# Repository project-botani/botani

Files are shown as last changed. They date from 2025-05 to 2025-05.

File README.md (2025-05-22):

# B.O.T.A.N.I - Beobachtender Organischer Topf mit Agiler Navigation und Intelligenz

A smart robotic system for remote plant care, navigation, and monitoring, designed using Raspberry Pis, sensors, and a LEGO vehicle base. B.O.T.A.N.I allows users to drive a plant-bearing vehicle via a custom-built controller equipped with a joystick, LED indicators, a buzzer, and a live video feed.

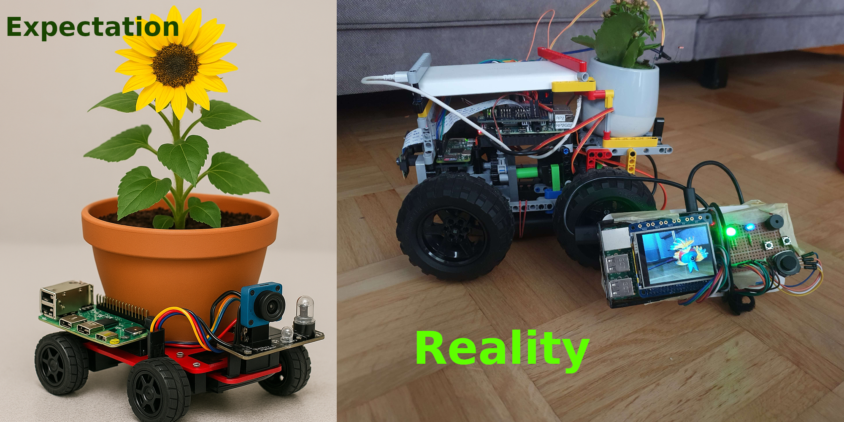
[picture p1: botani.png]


## Project Structure

```
.
├── RaspberryPi3        # Controller hardware: joystick, display, buzzer, LED
│   ├── view_stream.py
│   ├── joystick.py
│   ├── ledcontrol.py
│   └── requirements.txt
├── RaspberryPi4        # Vehicle logic: motors, camera, distance control
│   ├── camera.py
│   ├── motorsteerdistance.py
│   └── requirements.txt
├── RaspberryPiZero     # Sensor node: brightness, temperature, humidity, distance
│   ├── sensors.py
│   └── requirements.txt
├── Dashboard.html      # Web dashboard for live feed and sensor data
├── README.md
└── ProjectReport.pdf   # Full project report
```

## System Overview

B.O.T.A.N.I consists of three main components:

1. **Controller** - A Raspberry Pi 3 with:

   * A PiTFT screen for live video.
   * Joystick for manual control.
   * RGB LED for temperature indication.
   * Buzzer for soil humidity alerts.

2. **Car Platform** - A LEGO-based vehicle powered by Raspberry Pi 4:

   * Servo motors for movement and steering.
   * Time-of-Flight sensor for collision avoidance.
   * Camera for live video stream.

3. **Sensor Node** - Raspberry Pi Zero:

   * Monitors light, temperature, humidity, and distance.
   * Publishes data via MQTT to the controller and web dashboard.

## How to set up the project

To configure all raspberry PIs, this repository needs to be cloned onto each one of them.
This repo contains folders that correspond to the code that needs to run on each one of the PIs.

### 1. Raspberry Pi 3 - Controller

**Dependencies:**

```bash
cd RaspberryPi3
python3 -m venv .venv --system-site-packages
source .venv/bin/activate
pip install -r requirements.txt
```

**Joystick Setup:**

```bash
sudo raspi-config  # Enable I2C
sudo apt install -y i2c-tools
i2cdetect -y 1     # Should detect ADC at 0x48
```

**Configure PiTFT Display:**

```bash
# Install display driver
sudo apt-get update
sudo apt-get install -y git python3-pip
pip3 install --upgrade adafruit-python-shell click
git clone https://github.com/adafruit/Raspberry-Pi-Installer-Scripts.git
cd Raspberry-Pi-Installer-Scripts

sudo -E env PATH=$PATH python3 adafruit-pitft.py --display=28r --rotation=90 --install-type=console

sudo reboot

# Configure rotation if necessary
# (look for line with the tft screen listed)
vim /boot/firmware/config.txt
sudo reboot
```

**Start All Scripts:**

```bash
python3 joystick.py & python3 ledcontrol.py & python3 view_stream.py
```

### 2. Raspberry Pi 4 - Car System

**Dependencies:**

```bash
cd RaspberryPi4
python3 -m venv .venv
source .venv/bin/activate
pip install -r requirements.txt
```

**Run:**

* `camera.py` for streaming video to `http://<car-ip>:8080/`
* `motorsteerdistance.py` to handle drive + safety logic

```bash
python3 camera.py & python3 motorsteerdistance.py
```

### 3. Raspberry Pi Zero - Sensors

**Dependencies:**

```bash
cd RaspberryPiZero
python3 -m venv .venv
source .venv/bin/activate
pip install -r requirements.txt
```

**Run:**

```bash
python3 sensors.py
```

### 4. Dashboard

Open `Dashboard.html` in a somewhat modern browser.
This file is standalone and does not require to be served by a webserver.
Make sure MQTT broker is accessible at `ws://<rpi4-ip>:8081`.

## Communication Overview

### MQTT Topics

| Topic | Publisher | Subscriber(s) | Purpose |
| --- | --- | --- | --- |
| `Brightness`  | Raspberry Pi Zero | Pi 3 (LED), Dashboard | Plant light level |
| `Temperature` | Raspberry Pi Zero | Pi 3 (RGB LED), Dashboard | Ambient temperature |
| `Humidity` | Raspberry Pi Zero | Pi 3 (Piezo buzzer), Dashboard | Soil moisture |
| `Distance` | Raspberry Pi Zero | Pi 4 (Safety), Dashboard | Obstacle distance |
| `joystick/xy` | Raspberry Pi 3 | Pi 4 (motor control) | Drive/steering commands |

### Video Stream

* The MJPEG stream is accessible at `http://<car-ip>:8080/`

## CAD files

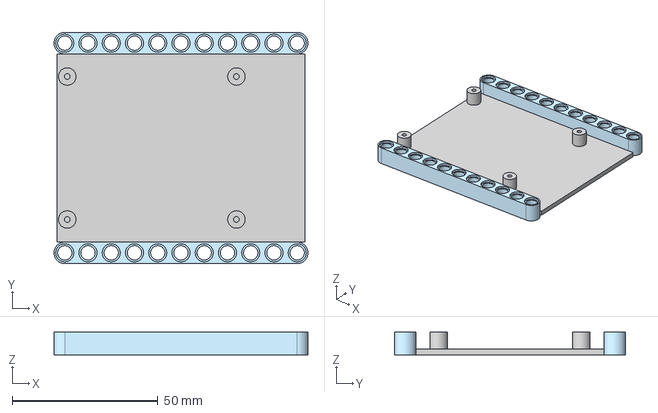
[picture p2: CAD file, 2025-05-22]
3DModels/RaspberryPiLegoMount.step
87.1 x 79.3 x 7.76 mm

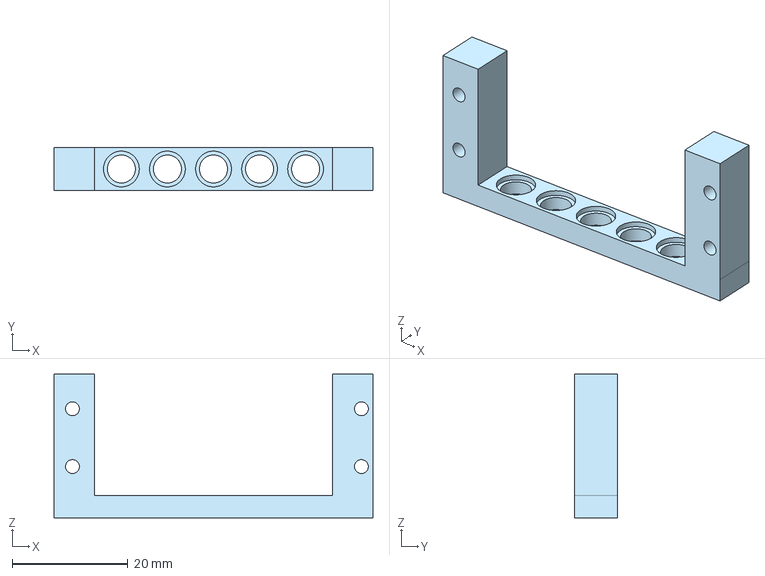
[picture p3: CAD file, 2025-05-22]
3DModels/MotorMount_Steering.step
55.2 x 7.38 x 24.9 mm

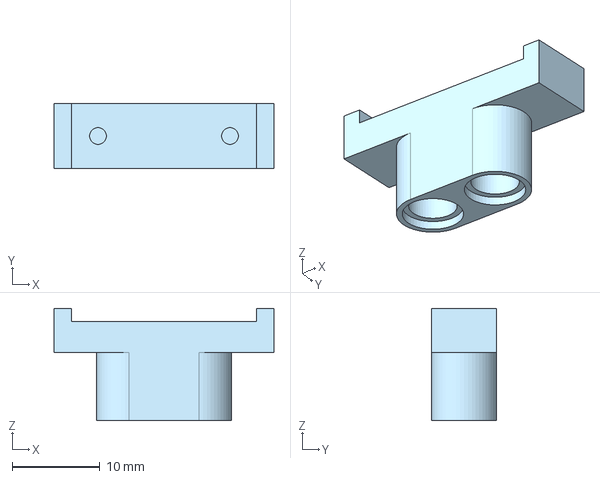
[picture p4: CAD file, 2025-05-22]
3DModels/ToF_Mount.step
25.0 x 7.38 x 12.8 mm

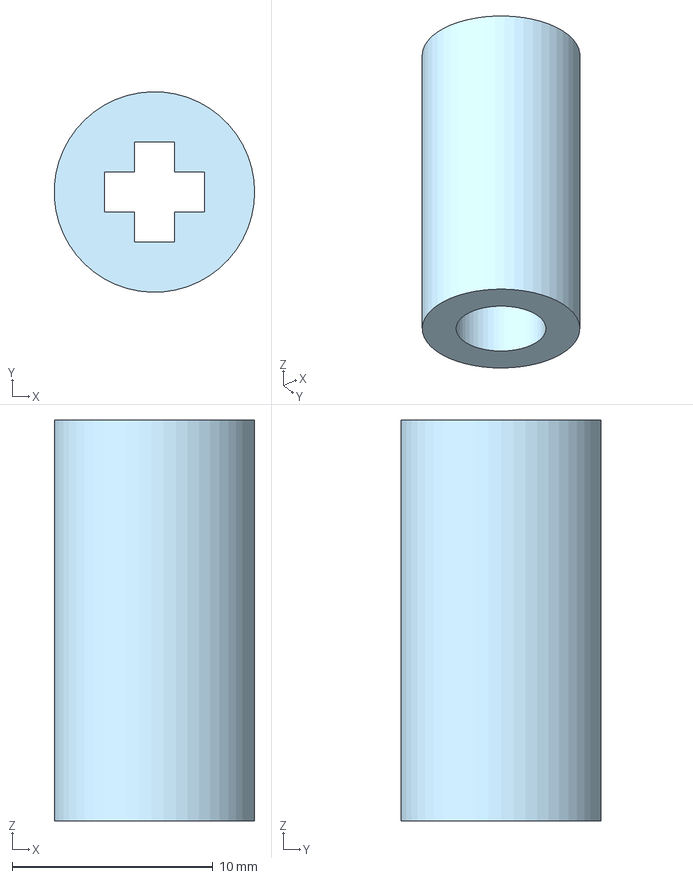
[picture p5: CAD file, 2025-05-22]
3DModels/ServoToLegoAxleInput.step
9.99 x 10.00 x 20.0 mm

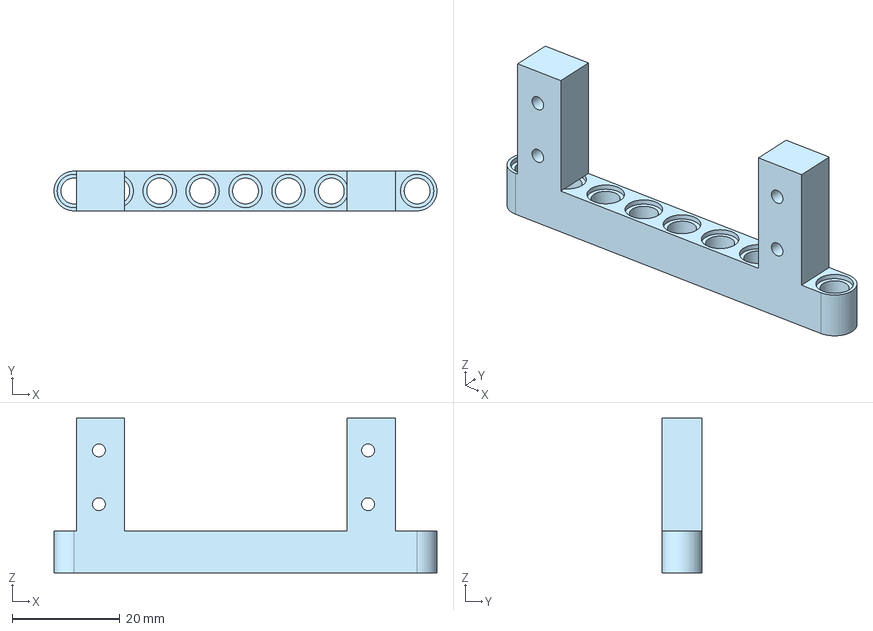
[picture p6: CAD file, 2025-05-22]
3DModels/MotorMount_Drive.step
71.1 x 7.38 x 28.8 mm

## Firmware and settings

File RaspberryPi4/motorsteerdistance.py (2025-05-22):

import json
import signal
import sys
import time
import threading

import paho.mqtt.client as mqtt
from adafruit_servokit import ServoKit

MQTT_BROKER      = "localhost"
MQTT_PORT        = 1883
JOYSTICK_TOPIC   = "joystick/xy"
DISTANCE_TOPIC   = "Distance"

STEER_SERVO_CH       = 13
DRIVE_SERVO_CH       = 15
DEAD_ZONE            = 0.05
STEER_SPEED          = 0.09
STEER_TRAVEL_TIME_L  = 0.9
STEER_TRAVEL_TIME_R  = 1.0
LOOP_INTERVAL        = 0.02
RECONNECT_DELAY      = 5

kit = ServoKit(channels=16)

_current_x = 0.0
_target_x  = 0.0
_distance  = 255
_lock      = threading.Lock()
_running   = True

def clamp(v, lo=-1.0, hi=1.0):
    return max(lo, min(hi, v))

def on_connect(client, _userdata, _flags, rc):
    client.subscribe(JOYSTICK_TOPIC)
    client.subscribe(DISTANCE_TOPIC)

def on_disconnect(client, _userdata, rc):
    while _running:
        try:
            client.reconnect()
            return
        except Exception:
            time.sleep(RECONNECT_DELAY)

def on_message(client, _userdata, msg):
    global _target_x, _distance

    topic = msg.topic
    payload = msg.payload.decode().strip()

    if topic == DISTANCE_TOPIC:
        try:
            d = float(payload)
            if 0.00 <= d <= 255.00:
                _distance = d
        except ValueError:
            pass
        return

    if topic == JOYSTICK_TOPIC:
        try:
            if payload.startswith("{"):
                data = json.loads(payload)
                x, y = float(data["x"]), float(data["y"])
            else:
                x_str, y_str = payload.split(",", 1)
                x, y = float(x_str), float(y_str)

            x = 0.0 if abs(x) < DEAD_ZONE else clamp(x)
            y = 0.0 if abs(y) < DEAD_ZONE else clamp(y)

            raw_throttle = -y

            if _distance < 100 and raw_throttle > 0:
                raw_throttle = 0.0

            kit.continuous_servo[DRIVE_SERVO_CH].throttle = raw_throttle

            with _lock:
                _target_x = x

        except Exception:
            pass

def steering_loop():
    global _current_x, _running

    while _running:
        with _lock:
            target = _target_x
            current = _current_x

        dx = target - current
        if abs(dx) < 1e-3:
            kit.continuous_servo[STEER_SERVO_CH].throttle = 0.0
        else:
            direction = 1.0 if dx > 0 else -1.0
            units_per_sec = 1.0 / (STEER_TRAVEL_TIME_R if direction > 0 else STEER_TRAVEL_TIME_L)
            kit.continuous_servo[STEER_SERVO_CH].throttle = STEER_SPEED * direction
            delta = direction * units_per_sec * LOOP_INTERVAL
            if abs(delta) >= abs(dx):
                _current_x = target
                kit.continuous_servo[STEER_SERVO_CH].throttle = 0.0
            else:
                _current_x = current + delta

        time.sleep(LOOP_INTERVAL)

def shutdown(_sig=None, _frame=None):
    global _running
    _running = False
    time.sleep(LOOP_INTERVAL * 2)
    kit.continuous_servo[STEER_SERVO_CH].throttle = 0.0
    kit.continuous_servo[DRIVE_SERVO_CH].throttle  = 0.0
    client.loop_stop()
    sys.exit(0)

signal.signal(signal.SIGINT, shutdown)
signal.signal(signal.SIGTERM, shutdown)

threading.Thread(target=steering_loop, daemon=True).start()

client = mqtt.Client()
client.on_connect    = on_connect
client.on_disconnect = on_disconnect
client.on_message    = on_message

while True:
    try:
        client.connect(MQTT_BROKER, MQTT_PORT, keepalive=60)
        break
    except Exception:
        time.sleep(RECONNECT_DELAY)

client.loop_start()

try:
    while True:
        time.sleep(1)
except KeyboardInterrupt:
    shutdown()

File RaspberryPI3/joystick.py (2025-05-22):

import board
import busio
import time
import paho.mqtt.publish as publish
import adafruit_ads1x15.ads1115 as ADS
from adafruit_ads1x15.analog_in import AnalogIn

i2c = busio.I2C(board.SCL, board.SDA)
ads = ADS.ADS1115(i2c)
chan_x = AnalogIn(ads, ADS.P0)
chan_y = AnalogIn(ads, ADS.P1)

minx = 3461
maxx = 21160
miny = 3207
maxy = 20522

threshx = 0.06
threshy = 0.11

def get_xy():
    x = ((chan_x.value - minx) / (maxx - minx)) * 2 - 1
    y = ((chan_y.value - miny) / (maxy - miny)) * 2 - 1

    x = 0 if abs(x) < threshx else x
    y = 0 if abs(y) < threshy else y

    return x, y

while True:
    x, y = get_xy()
    try:
        publish.single(
            "joystick/xy",
            f"{x:.3f},{y:.3f}",
            hostname="192.168.31.178",
            port=1883
        )
    except:
        pass
    time.sleep(0.05)

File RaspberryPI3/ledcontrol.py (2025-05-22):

import threading
import time
import RPi.GPIO as GPIO
import paho.mqtt.client as mqtt
from gpiozero import PWMLED, DigitalOutputDevice

LED_BRIGHT_PIN = 22
LED_R_PIN      = 4
LED_G_PIN      = 17
LED_B_PIN      = 27
BUZZER_PIN     = 23
BUTTON_PIN     = 14   
BUTTON2_PIN    = 15   

LUX_MIN   = 0
LUX_MAX   = 1000
TEMP_COLD = 15
TEMP_HOT  = 28

led_brightness = PWMLED(LED_BRIGHT_PIN)
led_red        = PWMLED(LED_R_PIN)
led_green      = PWMLED(LED_G_PIN)
led_blue       = PWMLED(LED_B_PIN)
buzzer         = DigitalOutputDevice(BUZZER_PIN)

GPIO.setmode(GPIO.BCM)
GPIO.setup(BUTTON_PIN, GPIO.IN, pull_up_down=GPIO.PUD_UP)
GPIO.setup(BUTTON2_PIN, GPIO.IN, pull_up_down=GPIO.PUD_UP)

buzzer_blinking = False
disable_buzzer  = False

def _button_poller():
    global disable_buzzer, buzzer_blinking
    while True:
        if GPIO.input(BUTTON_PIN) == GPIO.LOW:
            disable_buzzer   = True
            buzzer.off()
            buzzer_blinking  = False
            while GPIO.input(BUTTON_PIN) == GPIO.LOW:
                time.sleep(0.05)
        time.sleep(0.05)

threading.Thread(target=_button_poller, daemon=True).start()

def scale_lux_to_pwm(lux):
    lux = max(LUX_MIN, min(lux, LUX_MAX))
    return lux / LUX_MAX

def temperature_to_rgb(temp):
    if temp <= TEMP_COLD:
        return (0.0, 0.0, 1.0)
    if temp >= TEMP_HOT:
        return (1.0, 0.0, 0.0)
    if temp < 22:
        ratio = (temp - TEMP_COLD) / (22 - TEMP_COLD)
        return (0.0, ratio, 1.0 - ratio)
    ratio = (temp - 22) / (TEMP_HOT - 22)
    return (ratio, 1.0 - ratio, 0.0)

def set_rgb(r, g, b):
    led_red.value   = r
    led_green.value = g
    led_blue.value  = b

def on_message(client, userdata, msg):
    global buzzer_blinking, disable_buzzer
    topic = msg.topic

    try:
        value = float(msg.payload.decode())
    except ValueError:
        return

    if topic == MQTT_TOPIC_BRIGHT:
        led_brightness.value = scale_lux_to_pwm(value)
    elif topic == MQTT_TOPIC_TEMP:
        set_rgb(*temperature_to_rgb(value))
    elif topic == MQTT_TOPIC_HUMID:
        if value < 50:
            if not disable_buzzer and not buzzer_blinking:
                buzzer.blink(on_time=0.5, off_time=0.5)
                buzzer_blinking = True
        else:
            disable_buzzer = False
            if buzzer_blinking:
                buzzer.off()
                buzzer_blinking = False

MQTT_BROKER        = "rpi4"
MQTT_TOPIC_BRIGHT = "Brightness"
MQTT_TOPIC_TEMP   = "Temperature"
MQTT_TOPIC_HUMID  = "Humidity"

def on_disconnect(client, userdata, rc):
    if rc != 0:
        reconnect()

client = mqtt.Client()
client.on_message = on_message
client.on_disconnect = on_disconnect

def reconnect():
    while True:
        try:
            client.connect(MQTT_BROKER, 1883, 5)
            client.subscribe([
                (MQTT_TOPIC_BRIGHT, 0),
                (MQTT_TOPIC_TEMP,   0),
                (MQTT_TOPIC_HUMID,  0),
            ])
            break
        except Exception:
            time.sleep(5)

reconnect()

try:
    client.loop_forever()
except KeyboardInterrupt:
    pass
finally:
    led_brightness.off()
    set_rgb(0, 0, 0)
    buzzer.off()
    GPIO.cleanup()
    client.disconnect()
